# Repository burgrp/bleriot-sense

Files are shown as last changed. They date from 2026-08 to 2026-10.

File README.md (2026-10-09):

# BleRiot Sense

BleRiot Sense is a compact single-sensor BleRiot node built around a
`PY32F003L16S6TU` microcontroller and a PAN2110 long-range 2.4 GHz radio. Its
sensor input is configured at assembly time for one of four uses:

- A 10 kΩ B3950 NTC thermistor.
- A pulse-output flow sensor such as the YF-B10.
- A pressure sensor with a driven 0.5-5 V analog output.
- An externally powered DS18B20 digital thermometer.

The assembly population and the firmware mode must agree. The hardware does not
switch sensor modes electronically at runtime.

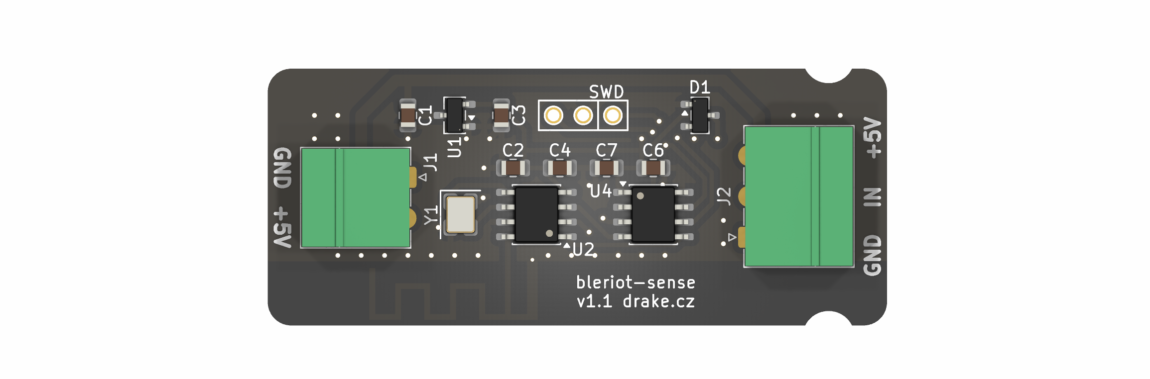
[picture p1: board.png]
BleRiot Sense board front render

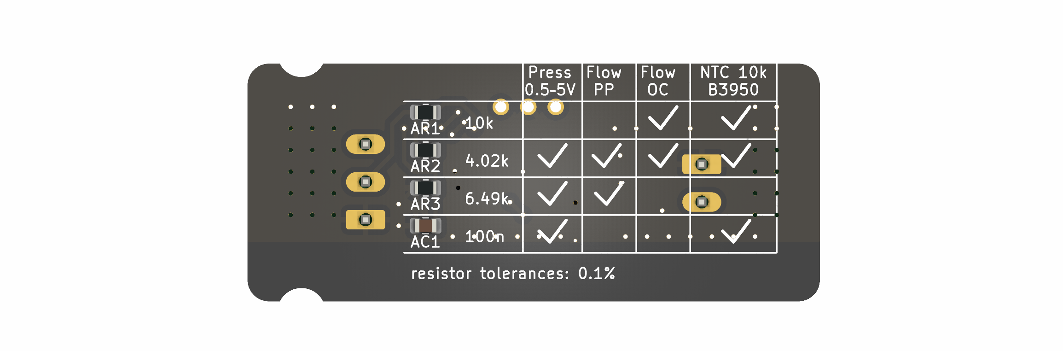
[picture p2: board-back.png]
BleRiot Sense board back with sensor-mode assembly table


## Repository layout

| Path | Description |
|---|---|
| [`board/bleriot-sense.kicad_pro`](board/bleriot-sense.kicad_pro) | `PY32F003L16S6TU` hardware |
| [`fw/`](fw/README.md) | Importable Sense firmware and board-owned build profile |
| [`fw/cmd/dev/`](fw/cmd/dev/) | Local inventory and BleRiot CLI |
| [`ANALOG-INPUT.md`](ANALOG-INPUT.md) | Configurable input circuit, populations, calculations, protection, and layout |
| [`sub/hw-kicad/`](sub/hw-kicad) | Shared KiCad symbols and footprints, included as a Git submodule |

## Sensor modes

| Mode | Node measurement | Registry value |
|---|---|---|
| NTC | Averaged 12-bit ADC code | Temperature in °C |
| Flow | Rising-edge pulse count | Frequency in Hz and cumulative pulse count |
| Pressure | Averaged 12-bit ADC code | Reconstructed sensor-output voltage in V |
| DS18B20 | Up to 20 signed Q12.4 scratchpad values | Temperature registers in °C |

See [`ANALOG-INPUT.md`](ANALOG-INPUT.md) before assembling a board. It defines
the required values for `AR1`, `AR2`, `AR3`, and `AC1`, including the two
alternative flow-sensor output circuits.

The pressure transfer function and flow K-factor depend on the exact sensor.
The hub currently exposes pressure input voltage and flow frequency without
assuming undocumented sensor calibration constants.

## Firmware status

[`fw`](fw/README.md) targets the `PY32F003L16S6TU` and uses `PA0` for
the universal sensor input. The NTC path has been verified end to end on
hardware through the ADC, PAN2110 radio, MCP2210 hub dongle, BleRiot hub,
conversion layer, and Registry. The single-sensor DS18B20 path has also been
verified end to end through its 1-Wire bus and the same radio/Registry path;
multidrop behavior still requires hardware validation. Flow and pressure support build and have
host-side conversion coverage but still require mode-specific hardware tests.

DS18B20 firmware prints discovered ROM IDs over RTT at boot. A single sensor
needs no configured ID; multidrop inventories map each temperature register to
an explicit ID. See the firmware README for configuration and timing details.

The upstream TinyGo `py32f003x6` target provides the required 1 KiB system
stack. The firmware runs without a task scheduler. See the firmware README for
pin assignments, first-boot option-byte handling, configuration, and memory
constraints.

## Getting started

Initialize the shared KiCad library after cloning:

```sh
git submodule update --init --recursive
```

Open the hardware project in KiCad:

```sh
kicad board/bleriot-sense.kicad_pro
```

Configure `sensorMode` in
[`fw/cmd/dev/main.go`](fw/cmd/dev/main.go), then test and build the firmware:

```sh
go -C fw test ./...
go -C fw run ./cmd/dev node build --name sense
```

Flash with a supported SWD probe:

```sh
go -C fw run ./cmd/dev node build --name sense --flash --rtt
```

With a Registry server running, start the hub in a separate terminal:

```sh
go -C fw run ./cmd/dev hub --registry http://localhost:8080 --diagnostics rf
```

For an NTC-configured node, read live temperatures:

```bash
export REGISTRY=http://localhost:8080
reg get sense.temperature --stay
```

## Toolchain

- KiCad 10 for the hardware projects.
- Go 1.25.2 or newer for the firmware inventory, generator, tests, and hub.
- TinyGo with the Puya `py32f003x6` target.
- pyOCD with the Puya CMSIS pack and a supported SWD probe.
- An MCP2210/PAN2110 BleRiot hub dongle for RF operation.
- The [`reg`](https://github.com/burgrp/reg) Registry service and CLI.

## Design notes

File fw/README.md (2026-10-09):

# BleRiot Sense firmware

This module is the importable BleRiot Sense firmware and local inventory for the
`PY32F003L16S6TU` hardware in `board`.

External hubs import the versioned device specification as:

```go
import sense "github.com/burgrp/bleriot-sense/fw/v2/spec"
```

- MCU: `PY32F003L16S6TU` (32 KiB flash, 4 KiB RAM).
- TinyGo and pyOCD target: `py32f003x6`.
- Sensor input: `PA0`.
- PAN2110 SCK: `PA1`.
- PAN2110 DATA: `PA2`.
- PAN2110 CSN: `PB0`.

## Sensor mode

Set `senseConfig` in `cmd/dev/main.go` to match the assembled input network.
Build the device type from the same value so its register table matches the
baked firmware configuration:

```go
var senseConfig = spec.Config{
	Mode:                       spec.ModeNTC,
	SampleIntervalMilliseconds: 1000,
	ADCSamples:                 16,
}

Type:   spec.TypeForConfig(senseConfig, spec.Calibration{}),
Config: senseConfig,
```

Supported values are:

| Mode | Assembly population | Registry values |
|---|---|---|
| `spec.ModeNTC` | AR1 10 kΩ, AR2 4.02 kΩ, AR3 DNP, AC1 100 nF | `temperature` in °C |
| `spec.ModeFlow` | Driven: AR1 DNP, AR2 4.02 kΩ, AR3 6.49 kΩ, AC1 DNP; open collector: AR1 10 kΩ, AR2 4.02 kΩ, AR3/AC1 DNP | `frequency` in Hz and cumulative `pulses` |
| `spec.ModePressure` | AR1 DNP, AR2 4.02 kΩ, AR3 6.49 kΩ, AC1 100 nF | Sensor-output `voltage` in V |
| `spec.ModeDS18B20` | AR1 4.7 kΩ, AR2 100 Ω, AR3/AC1 DNP | `temperature` in °C |

The mode is inventory-as-code and is baked into the image by `node build`. It
does not electronically change the assembly population at runtime. Rebuild and
flash the node after changing it.

NTC and pressure calculations run in the hub; the node transmits averaged raw
12-bit ADC codes. Flow frequency is transmitted in millihertz and converted to
hertz by the hub. A sensor-specific pressure transfer function or flow K-factor
can be added to the host conversion once the exact sensor calibration is known.

DS18B20 mode supports up to 20 externally powered devices. Connect all sensors
in parallel: J2 pin 1 to GND, pin 2 to DQ, and pin 3 to VDD. DQ is pulled up to
3.3 V; do not connect a 5 V DQ pull-up. Parasite power is not supported.

At every boot, firmware enumerates the bus and prints copy-pasteable IDs over
RTT before starting the radio:

```text
DS18B20 ID: [8]byte{40, 255, 100, 30, 147, 22, 4, 128}
```

One temperature register needs no configured ID. It binds automatically only
when exactly one DS18B20 is discovered. For multiple registers, configure every
ID in register order:

```go
var senseConfig = spec.Config{
	Mode:                       spec.ModeDS18B20,
	SampleIntervalMilliseconds: 1000,
	DS18B20Sensors: []spec.DS18B20Sensor{
		{ID: [8]byte{40, 255, 100, 30, 147, 22, 4, 128}},
		{ID: [8]byte{40, 2, 2, 3, 4, 5, 6, 199}},
	},
}
```

Optional per-register calibration is supplied only when constructing the host
device type. It is not part of `spec.Config`, is not baked into firmware, and
does not alter the signed Q12.4 value returned by the node:

```go
var senseCalibration = spec.Calibration{
	DS18B20: map[int]float64{
		3: 1,
	},
}

Type:   spec.TypeForConfig(senseConfig, senseCalibration),
Config: senseConfig,
```

The hub publishes $raw/16 + OffsetCelsius$. Supply either no calibration entries
or sparse offsets keyed by one-based DS18B20 sensor index, matching register names
such as `temperature.3`. Indexes must identify configured registers, offsets must
be finite, and nonzero offsets are included in Registry metadata as
`offsetCelsius`.

DS18B20 registers use the dedicated contiguous tag range 256–275. A one-register
inventory uses `temperature`; a multidrop inventory uses `temperature.1` through
`temperature.20`. Generic sample tag 1 and flow pulse-count tag 2 remain separate.
Per-instance `RegistryNames` may assign meaningful deployment names without
changing these wire identities.

The node validates ROM and scratchpad CRCs and transmits signed Q12.4 values.
It broadcasts one conversion, waits 800 ms while polling the radio, then reads
one addressed sensor per main-loop pass. One 12-bit addressed read takes about
11.7 ms; `bleNode.Poll()` runs between reads, so 20 sensors do not create one
continuous roughly 234 ms radio blackout. With all 20 sensors, the 800 ms
conversion plus addressed reads stretches a nominal 1 s cycle to about 1.04 s.
A failed sensor becomes null without invalidating successful readings from the
other sensors.

The protocol implementation comes from `github.com/burgrp/tinygo-drivers/onewire`.
This board supplies only the PA0 open-drain, TIM3 1 MHz counter, and interrupt
adapter in `onewire_py32.go`.

The node retains the latest full-resolution sample for scheduled GET responses.
In flow mode, the pulse interrupt only increments an in-memory counter; each
sample interval updates both the frequency and cumulative `pulses` register.

NTC and pressure modes reply with protocol NULL for averaged ADC codes at or
below 64 or at or above 4031. An open NTC is pulled high; an open pressure input
is pulled low. The pressure sensor's documented 0.5–5.25 V range remains inside
these thresholds. Hub-side NTC checks remain as a defensive fallback.

DS18B20 scratchpad/address failures null only the affected register. No-presence,
stuck-low, parasite-power, or broadcast-conversion failures null the whole bus.
Flow is the hardware exception: no pulses is electrically identical to an
unplugged sensor, so firmware preserves a valid `0 Hz` reading. True flow-sensor
presence detection requires an additional hardware signal or heartbeat.

## Build and run

From this directory:

```sh
go test ./...
go run ./cmd/dev node gen --name sense
go run ./cmd/dev node build --name sense --disassembly
go run ./cmd/dev node build --name sense --flash --rtt
```

Run the hub against a Registry server with:

```sh
go run ./cmd/dev hub --registry http://localhost:8080 --diagnostics rf
```

The build command creates a private module under `.bleriot/firmware/sense`,
generates the node entry point, and calls `sense.Run` with the RF identity and
baked `spec.Config`.

The upstream TinyGo `py32f003x6` target reserves a 1 KiB system stack. Firmware
uses `--scheduler none`; sensor acquisition shares the nonblocking node loop so
no heap-backed goroutine stacks are required.

## First boot

On the eight-pin package, the PAN2110 CSN pad is shared with `PF2-NRST`. On first
boot the firmware preserves all option bytes except `NRST_MODE`, changes that
one option to GPIO, and requests one option-byte reload reset. Later boots do
not write the option bytes. SWD remains available on the separate SWDIO and
SWCLK pads.

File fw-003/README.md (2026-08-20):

# BleRiot Sense firmware

This module is the BleRiot node and hub inventory for the `board-003` hardware
variant. The sibling `board-030` project uses a PY32F030 and requires separate
firmware.

External hubs import the versioned device specification as:

```go
import sense "github.com/burgrp/bleriot-sense/fw-003/spec"
```

- MCU: `PY32F003L16S6TU` (32 KiB flash, 4 KiB RAM).
- TinyGo and pyOCD target: `py32f003x6`.
- Sensor input: `PA0`.
- PAN2110 SCK: `PA1`.
- PAN2110 DATA: `PA2`.
- PAN2110 CSN: `PB0`.

## Sensor mode

Set `sensorMode` in `test-hub.go` to match the assembled input network. The
device type needs only that mode; timing and averaging remain inline in the
firmware configuration:

```go
const sensorMode = spec.ModeNTC

Type: spec.Type(sensorMode),
Config: spec.Config{
	Mode:                       sensorMode,
	SampleIntervalMilliseconds: 1000,
	ADCSamples:                 16,
	SampleHysteresis:           4,
},
```

Supported values are:

| Mode | Assembly population | Registry values |
|---|---|---|
| `spec.ModeNTC` | AR1 10 kΩ, AR2 4.02 kΩ, AR3 DNP, AC1 100 nF | `temperature` in °C |
| `spec.ModeFlow` | Driven: AR1 DNP, AR2 4.02 kΩ, AR3 6.49 kΩ, AC1 DNP; open collector: AR1 10 kΩ, AR2 4.02 kΩ, AR3/AC1 DNP | `frequency` in Hz and cumulative `pulses` |
| `spec.ModePressure` | AR1 DNP, AR2 4.02 kΩ, AR3 6.49 kΩ, AC1 100 nF | Sensor-output `voltage` in V |

The mode is inventory-as-code and is baked into the image by `bleriot make`. It
does not electronically change the assembly population at runtime. Rebuild and
flash the node after changing it.

NTC and pressure calculations run in the hub; the node transmits averaged raw
12-bit ADC codes. Flow frequency is transmitted in millihertz and converted to
hertz by the hub. A sensor-specific pressure transfer function or flow K-factor
can be added to the host conversion once the exact sensor calibration is known.

`SampleHysteresis` reduces RF traffic by comparing each sample with the last
notified sample. A notification is sent only when the absolute difference is at
least the configured threshold. `0` and `1` preserve notification on every raw
change. The threshold uses node wire units: ADC counts in NTC and pressure
modes, and millihertz in flow mode. The example value of four ADC counts is
approximately 0.09 °C near 25 °C for the specified thermistor. GET responses
retain the latest full-resolution sample.

In flow mode, the pulse interrupt only increments an in-memory counter. The
cumulative `pulses` register is sampled and can notify at most once per sample
interval while pulses are arriving; it does not send one notification per
physical pulse. `SampleHysteresis` applies to `frequency`, not to `pulses`.

## Build and run

From this directory:

```sh
go test ./...
go run . make sense build
go run . make sense flash
```

Run the hub against a Registry server with:

```sh
go run . hub --registry http://localhost:8080 --diagnostics rf
```

The build command generates the ignored `main_gen.go` containing the node's RF
identity and baked `spec.Config`.

The upstream TinyGo `py32f003x6` target reserves a 1 KiB system stack. Firmware
uses `--scheduler none`; sensor acquisition shares the nonblocking node loop so
no heap-backed goroutine stacks are required.

## First boot

On the eight-pin package, the PAN2110 CSN pad is shared with `PF2-NRST`. On first
boot the firmware preserves all option bytes except `NRST_MODE`, changes that
one option to GPIO, and requests one option-byte reload reset. Later boots do
not write the option bytes. SWD remains available on the separate SWDIO and
SWCLK pads.

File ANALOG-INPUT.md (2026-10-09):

# Universal sensor input

## Purpose

The board uses one configurable input circuit for four mutually exclusive sensor modes:

1. A pressure sensor with a driven 0.5–5 V analog output.
2. A YF-B10 flow sensor with a pulse output.
3. An external 10 kΩ, B3950 NTC thermistor.
4. An externally powered DS18B20 digital thermometer.

The operating mode is selected by component population when the board is assembled. It is not switched electronically at runtime.

## Common circuit

```text
                        AR1
                 +3V3 ─/\/\/─+
                              |
                              +──── INPUT ─── AR2 ───+──── SENSOR_OUT ─── MCU
                              |                     |
                       external sensor              +── AR3 ── GND
                              |                     |
                             GND                    +── AC1 ── GND
```

`AR3` and `AC1` are separate parallel branches from `SENSOR_OUT` to ground. They are not connected in series.

The sensor connector should provide:

| Pin | Signal | Description |
|---:|---|---|
| 1 | `GND` | Sensor ground |
| 2 | `INPUT` | Driven sensor output, flow pulse, NTC terminal, or DS18B20 DQ |
| 3 | `+5V_SENSOR` | Supply for a pressure, flow, or DS18B20 sensor |

In NTC mode, the thermistor connects between `INPUT` and ground. The `+5V_SENSOR` pin is unused. `AR1` connects to regulated `+3V3`, making the measurement ratiometric with the MCU ADC supply.

## Recommended component values

| Component | Nominal value | Function |
|---|---:|---|
| AR1 | 10.0 kΩ, 0.1% | NTC or open-collector flow pull-up |
| AR2 | 4.02 kΩ, 0.1% | Input scaling, isolation, and fault-current limiting |
| AR3 | 6.49 kΩ, 0.1% | Lower resistor of the 5 V input divider |
| AC1 | 100 nF | Analog low-pass filter |

Use low-temperature-coefficient resistors for pressure and temperature measurement. One-percent parts may be sufficient if the assembled board is calibrated.

## Population table

| Mode | AR1 | AR2 | AR3 | AC1 | MCU input mode |
|---|---:|---:|---:|---:|---|
| Pressure, 0.5–5 V | DNP | 4.02 kΩ | 6.49 kΩ | 100 nF | ADC |
| Flow, driven 5 V output | DNP | 4.02 kΩ | 6.49 kΩ | DNP | GPIO/timer |
| Flow, open collector | 10.0 kΩ | 4.02 kΩ | DNP | DNP | GPIO/timer |
| NTC 10k B3950 | 10.0 kΩ | 4.02 kΩ | DNP | 100 nF | ADC |
| DS18B20 | 4.7 kΩ | 100 Ω | DNP | DNP | Open-drain GPIO |

The two flow populations are alternatives. Select one only after confirming the electrical output of the exact YF-B10 variant.

The DS18B20 population uses different resistor values from every analog mode.
Do not fit the default 4.02 kΩ `AR2` or 100 nF `AC1` in this mode.
The v1.2 board's back-side assembly legend predates DS18B20 support; use this
table rather than the values printed beside the footprints for a DS18B20 build.

## Pressure mode

### Population and connection

- Do not populate `AR1`.
- Populate `AR2` with 4.02 kΩ.
- Populate `AR3` with 6.49 kΩ.
- Populate `AC1` with 100 nF.
- Configure the MCU pin as an ADC input.
- Power the pressure sensor from `+5V_SENSOR` and connect its driven output to `INPUT`.

### Voltage scaling

`AR2` and `AR3` form a divider:

$$
V_{\mathrm{OUT}}=V_{\mathrm{INPUT}}\frac{R_{\mathrm{AR3}}}{R_{\mathrm{AR2}}+R_{\mathrm{AR3}}}
$$

For the recommended values:

$$
\frac{R_{\mathrm{AR3}}}{R_{\mathrm{AR2}}+R_{\mathrm{AR3}}}=\frac{6.49}{4.02+6.49}\approx0.6175
$$

| Sensor voltage | MCU voltage | Approximate 12-bit ADC code at 3.3 V |
|---:|---:|---:|
| 0.5 V | 0.309 V | 383 |
| 2.5 V | 1.544 V | 1916 |
| 4.5 V | 2.779 V | 3448 |
| 5.0 V | 3.087 V | 3831 |
| 5.25 V | 3.242 V | 4023 |

The original sensor voltage is recovered with:

$$
V_{\mathrm{INPUT}}=V_{\mathrm{OUT}}\frac{R_{\mathrm{AR2}}+R_{\mathrm{AR3}}}{R_{\mathrm{AR3}}}\approx1.6194V_{\mathrm{OUT}}
$$

The divider provides headroom for a nominal 5 V signal but does not make arbitrary overvoltage safe.

### Fault detection

`AR3` pulls `SENSOR_OUT` near ground when the pressure sensor or cable is
disconnected. The node replies with null for averaged ADC codes at or below 64
or at or above 4031. These thresholds are outside the documented 0.5–5.25 V
input range: its approximate codes are 383–4023.

### Filtering

For a low-impedance sensor output, the resistance driving `AC1` is approximately:

$$
R_{\mathrm{TH}}=R_{\mathrm{AR2}}\parallel R_{\mathrm{AR3}}\approx2.48\ \mathrm{k\Omega}
$$

With 100 nF:

$$
f_c=\frac{1}{2\pi R_{\mathrm{TH}}C_{\mathrm{AC1}}}\approx642\ \mathrm{Hz}
$$

$$
	au=R_{\mathrm{TH}}C_{\mathrm{AC1}}\approx248\ \mathrm{\mu s}
$$

Pressure normally changes slowly, so firmware can additionally average several ADC samples.

## Flow mode

The YF-B10 produces pulses whose frequency represents flow. The MCU pin must be configured as a digital GPIO interrupt, timer capture, or timer counter input—not as an ADC input. `AC1 = 100 nF` is not populated because it would slow pulse edges and could distort the duty cycle.

### Driven or internally pulled-up output

Use this population only if the exact sensor produces a driven pulse reaching approximately 5 V:

- Do not populate `AR1`.
- Populate `AR2` with 4.02 kΩ.
- Populate `AR3` with 6.49 kΩ.
- Do not populate `AC1`.

The divider applies the same scale factor as pressure mode:

$$
V_{\mathrm{HIGH,OUT}}\approx0.6175V_{\mathrm{HIGH,INPUT}}
$$

A 5 V pulse becomes approximately 3.09 V; a 4.5 V pulse becomes approximately 2.78 V.

The sensor drives a total divider resistance of:

$$
R_{\mathrm{AR2}}+R_{\mathrm{AR3}}=10.51\ \mathrm{k\Omega}
$$

At 5 V, its high-state load current is approximately:

$$
I=\frac{5}{10.51\ \mathrm{k\Omega}}\approx0.476\ \mathrm{mA}
$$

Confirm that the sensor can source this current and that 2.78 V is safely above the MCU's guaranteed digital-high threshold under all operating conditions.

### Open-collector output

Some YF-B10 variants are described as NPN/open-collector outputs. Such an output needs a pull-up:

- Populate `AR1` with 10 kΩ to `+3V3`.
- Populate `AR2` with 4.02 kΩ.
- Do not populate `AR3`.
- Do not populate `AC1`.

`AR1` pulls `INPUT` to 3.3 V while the sensor transistor pulls it to ground. Since the MCU input draws negligible DC current, there is almost no DC drop across `AR2`, and the MCU receives a nominal 0–3.3 V pulse.

Before choosing the production population, verify the exact sensor's:

- Supply-voltage range.
- Push-pull/open-collector output type.
- Internal pull-up, if any.
- Output-high voltage and source current.
- Maximum pulse frequency.
- Required external pull-up resistance.

An optional 100 pF–1 nF capacitor footprint can be added for high-frequency EMI suppression. Its effect on pulse shape and maximum measurable frequency must be verified before population.

Firmware calculates flow by counting pulses in a fixed interval or measuring the time between edges. Use the calibration constant for the exact sensor, preferably verified by system calibration.

A disconnected flow sensor cannot be distinguished from a connected sensor at
zero flow using this single pulse wire: both produce no edges and the same idle
level for the selected population. Firmware therefore preserves `0 Hz` when no
pulses arrive. Reliable disconnect reporting requires a separate presence
signal, a sensor heartbeat, or supply-current sensing.

## NTC mode

### Population and connection

- Populate `AR1` with 10.0 kΩ, preferably 0.1% and low temperature coefficient.
- Populate `AR2` with 4.02 kΩ.
- Do not populate `AR3`.
- Populate `AC1` with 100 nF.
- Configure the MCU pin as an ADC input.
- Connect the external 10 kΩ B3950 NTC from `INPUT` to ground.

The temperature divider is:

```text
+3V3 ── AR1 10k ── INPUT ── external NTC 10k B3950 ── GND
```

`AR2` isolates the cable-side divider from the ADC and forms a low-pass filter with `AC1`. Since the ADC draws negligible DC current, `AR2` causes almost no steady-state voltage drop.

### Resistance calculation

The nominal ADC voltage is:

$$
V_{\mathrm{OUT}}\approx V_{\mathrm{CC}}\frac{R_{\mathrm{NTC}}}{R_{\mathrm{AR1}}+R_{\mathrm{NTC}}}
$$

At 25 °C, both `AR1` and the NTC are nominally 10 kΩ, so:

$$
V_{\mathrm{OUT}}=3.3\frac{10\ \mathrm{k\Omega}}{10\ \mathrm{k\Omega}+10\ \mathrm{k\Omega}}=1.65\ \mathrm{V}
$$

Thermistor resistance can be recovered from voltage:

$$
R_{\mathrm{NTC}}=R_{\mathrm{AR1}}\frac{V_{\mathrm{OUT}}}{V_{\mathrm{CC}}-V_{\mathrm{OUT}}}
$$

For a 12-bit ADC using the same supply as its reference, use the ratiometric form:

$$
R_{\mathrm{NTC}}=R_{\mathrm{AR1}}\frac{N_{\mathrm{ADC}}}{4095-N_{\mathrm{ADC}}}
$$

This result is largely independent of the exact 3.3 V supply voltage.

### Temperature calculation

For a nominal 10 kΩ B3950 thermistor:

$$
T_K=\left[\frac{1}{298.15}+\frac{1}{3950}\ln\left(\frac{R_{\mathrm{NTC}}}{10000}\right)\right]^{-1}
$$

Convert kelvin to degrees Celsius with:

$$
T_C=T_K-273.15
$$

Approximate nominal values are:

| Temperature | NTC resistance | ADC voltage at 3.3 V |
|---:|---:|---:|
| −20 °C | 105 kΩ | 3.01 V |
| 0 °C | 33.6 kΩ | 2.54 V |
| 25 °C | 10.0 kΩ | 1.65 V |
| 50 °C | 3.59 kΩ | 0.87 V |
| 80 °C | 1.27 kΩ | 0.37 V |
| 100 °C | 0.70 kΩ | 0.21 V |

Use the thermistor manufacturer's resistance table or Steinhart–Hart coefficients when better accuracy is required.

### Filtering

At 25 °C, the approximate resistance driving `AC1` is:

$$
R_{\mathrm{TH}}=R_{\mathrm{AR2}}+(R_{\mathrm{AR1}}\parallel R_{\mathrm{NTC}})=4.02\ \mathrm{k\Omega}+5.00\ \mathrm{k\Omega}=9.02\ \mathrm{k\Omega}
$$

With 100 nF:

$$
f_c\approx\frac{1}{2\pi(9.02\ \mathrm{k\Omega})(100\ \mathrm{nF})}\approx176\ \mathrm{Hz}
$$

This is much faster than the thermal response of a typical probe. Firmware averaging can provide additional noise rejection.

### Fault detection

Firmware should treat readings near either ADC rail as possible faults:

- Near 0 V: shorted thermistor/cable or temperature above the intended range.
- Near 3.3 V: open thermistor/cable or temperature below the intended range.

The node replies with null for averaged 12-bit ADC codes at or below 64 and at
or above 4031. These thresholds are well outside the nominal −20…100 °C range
while leaving margin for ADC and component tolerances. The hub conversion keeps
the same checks as a defensive fallback.

## DS18B20 mode

### Population and connection

- Populate `AR1` with 4.7 kΩ to `+3V3`.
- Populate `AR2` with 100 Ω.
- Do not populate `AR3` or `AC1`.
- Keep the MCU-side `D1` rail clamp populated.
- Connect DS18B20 GND to J2 pin 1, DQ to pin 2, and VDD to pin 3 (`+5V_SENSOR`).

The DQ pull-up is 3.3 V even though the sensor is powered from 5 V. Do not use a
probe or breakout that pulls DQ up to 5 V: `PA0` is not 5 V tolerant. The 100 Ω
series resistor provides edge damping and limits clamp current without preventing
the MCU from meeting the DS18B20 low-level requirement.

Firmware supports up to 20 externally powered DS18B20s connected in parallel.
Parasite-powered operation is not supported because the board has no switched
strong pull-up. Firmware checks the bus power mode and leaves temperature
registers null when a parasite-powered device is detected.

For a long or highly capacitive cable, 2.2–3.3 kΩ may be required for `AR1`.
Qualify the actual sensor count, cable topology, and any alternative pull-up with
an oscilloscope at the connector; DQ must rise in time for the firmware's 10 µs
read sample. Do not populate `AC1` as an EMI filter on the 1-Wire bus.

### Firmware behavior

At boot the node enumerates the 1-Wire bus and prints every DS18B20 ID over RTT.
It configures each selected sensor for 12-bit resolution without writing EEPROM,
broadcasts one conversion, and polls the radio during the 800 ms conversion.
Addressed scratchpads are then read one per main-loop pass, with another radio
poll between sensors. It transports native signed Q12.4 words; the hub converts
them to degrees Celsius. A missing device, bad CRC, or out-of-range value nulls
only that sensor. A stuck-low bus or parasite-power fault nulls the whole bus
until a later cycle succeeds.

## Input protection

The common four-component network does not by itself provide complete protection. Recommended additions are:

```text
connector INPUT ── cable ESD device ── AR2 ── SENSOR_OUT ── MCU
                                               |
                                      low-leakage clamps
                                        to +3V3 and GND
```

- Put a cable-rated, low-capacitance ESD device next to the connector.
- Its working voltage must not load a valid 5–5.25 V signal at `INPUT`.
- Put low-leakage rail clamps close to `SENSOR_OUT` and the MCU.
- Orient the lower clamp from ground to `SENSOR_OUT` and the upper clamp from `SENSOR_OUT` to `+3V3`.
- Keep `AR2` before the MCU-side clamps so it limits fault current.
- Check the clamp leakage over temperature because it contributes analog measurement error.
- Check unpowered behavior: an energized sensor must not back-power the 3.3 V rail through the upper clamp.

The circuit is intended for normal 0–5 V signals and transient protection. It is not automatically safe against a sustained 12 V or 24 V wiring error.

## PCB layout

- Place the cable ESD device immediately behind the sensor connector.
- Give the ESD device a short, direct connection to the ground plane.
- Place `AC1`, `AR3`, and MCU-side clamps close to the MCU input.
- Keep `SENSOR_OUT` away from the RF antenna, crystal, clocks, LED data, and noisy supply-current paths.
- Avoid sharing the sensor ground-return path with high-current LED, radio, or regulator currents.
- Provide test points for `INPUT` and `SENSOR_OUT`.
- Clearly document the pressure, flow, NTC, and DS18B20 assembly populations on the schematic and BOM.

## Firmware summary

| Mode | MCU peripheral | Processing |
|---|---|---|
| Pressure | ADC | Average samples and reverse the divider ratio |
| Flow | GPIO/timer | Count edges or measure pulse period |
| NTC | ADC | Convert ADC ratio to resistance and then temperature |
| DS18B20 | Open-drain GPIO | 1-Wire conversion and CRC-checked scratchpad read |

The selected MCU pin must support ADC, interrupt input, and open-drain GPIO operation if all four populations are to use exactly the same physical input.

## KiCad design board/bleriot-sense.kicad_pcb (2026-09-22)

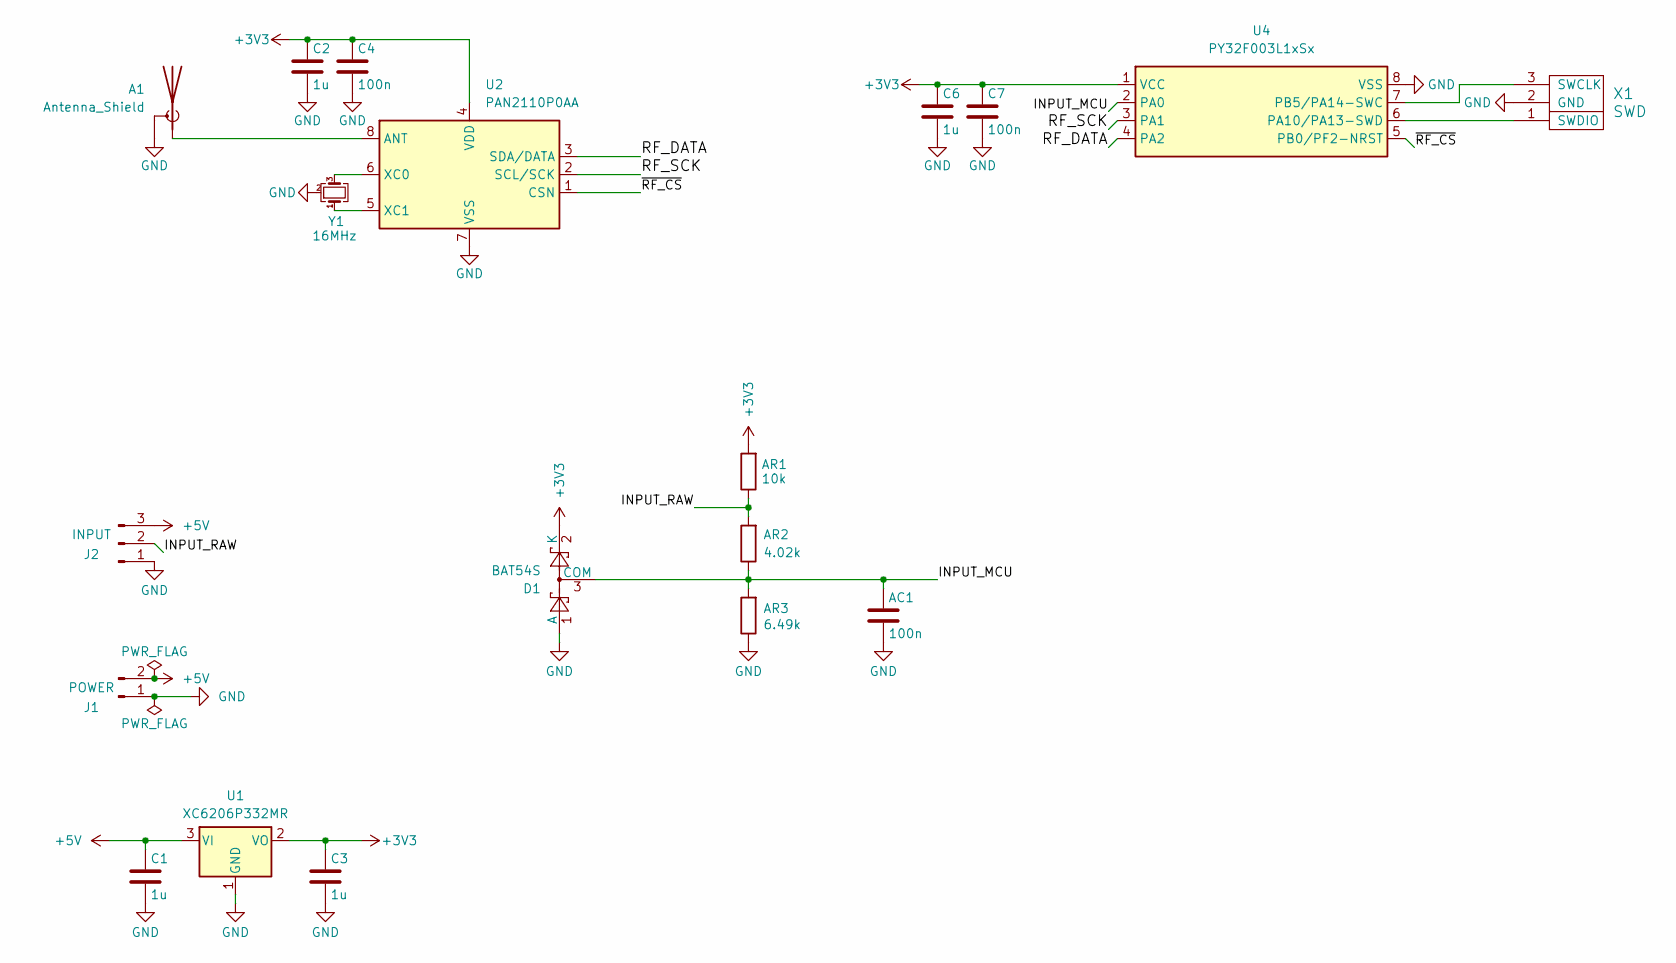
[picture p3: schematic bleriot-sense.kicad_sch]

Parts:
A1: Antenna_Shield; Texas_SWRA117D_2.4GHz_Left
AC1: 100n; C_0805_2012Metric
AR1: 10k; R_0805_2012Metric
AR2: 4.02k; R_0805_2012Metric
AR3: 6.49k; R_0805_2012Metric
C1, C2, C3, C6: 1u; C_0805_2012Metric
C4, C7: 100n; C_0805_2012Metric
D1: BAT54S; SOT-23
J1: POWER; PhoenixContact_MSTBA_2,5_2-G_1x02_P5.00mm_Horizontal
J2: INPUT; PhoenixContact_MSTBA_2,5_3-G_1x03_P5.00mm_Horizontal
U1: XC6206P332MR; SOT-23-3
U2: PAN2110P0AA; SOIC-8_3.9x4.9mm_P1.27mm
U4: PY32F003L1xSx; SOIC-8_3.9x4.9mm_P1.27mm
X1: SWD
Y1: 16MHz; Crystal_SMD_3225-4Pin_3.2x2.5mm

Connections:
+3V3: AR1.2, C2.1, C3.1, C4.1, C6.1, C7.1, D1.2 (K), U1.2 (VO), U2.4 (VDD), U4.1 (VCC)
+5V: C1.1, J1.2, J2.3, U1.3 (VI)
/INPUT_MCU: AC1.1, AR2.1, AR3.2, D1.3 (COM), U4.2 (PA0)
/INPUT_RAW: AR1.1, AR2.2, J2.2
/RF_DATA: U2.3 (SDA/DATA), U4.4 (PA2)
/RF_SCK: U2.2 (SCL/SCK), U4.3 (PA1)
/~RF_CS: U2.1 (CSN), U4.5 (PB0/PF2-NRST)
GND: A1.2 (Shield), AC1.2, AR3.1, C1.2, C2.2, C3.2, C4.2, C6.2, C7.2, D1.1 (A), J1.1, J2.1, U1.1 (GND), U2.7 (VSS), U4.8 (VSS), X1.2 (GND), Y1.2 (G), Y1.4 (G)
unnamed: A1.1 (A), U2.8 (ANT)
unnamed: U2.6 (XC0), Y1.3
unnamed: U2.5 (XC1), Y1.1
unnamed: U4.6 (PA10/PA13-SWD), X1.1 (SWDIO)
unnamed: U4.7 (PB5/PA14-SWC), X1.3 (SWCLK)

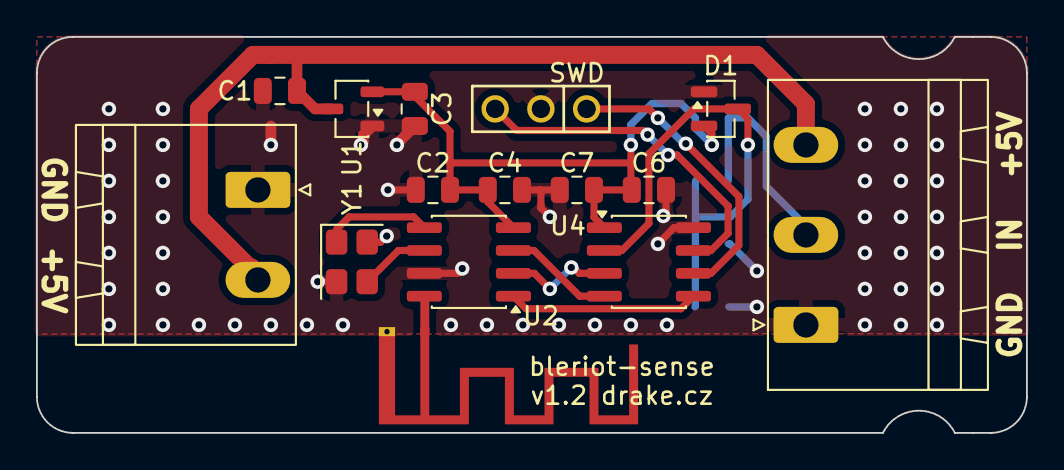
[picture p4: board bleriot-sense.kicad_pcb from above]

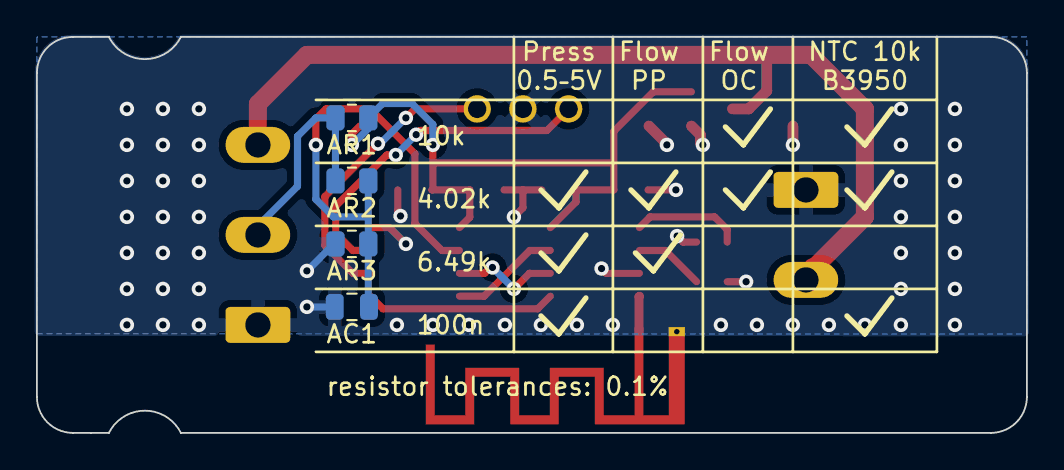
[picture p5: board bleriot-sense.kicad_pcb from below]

Board: 2 copper layers, 55.0 x 22.0 mm, 19 parts (4 on the bottom side), 13 nets.

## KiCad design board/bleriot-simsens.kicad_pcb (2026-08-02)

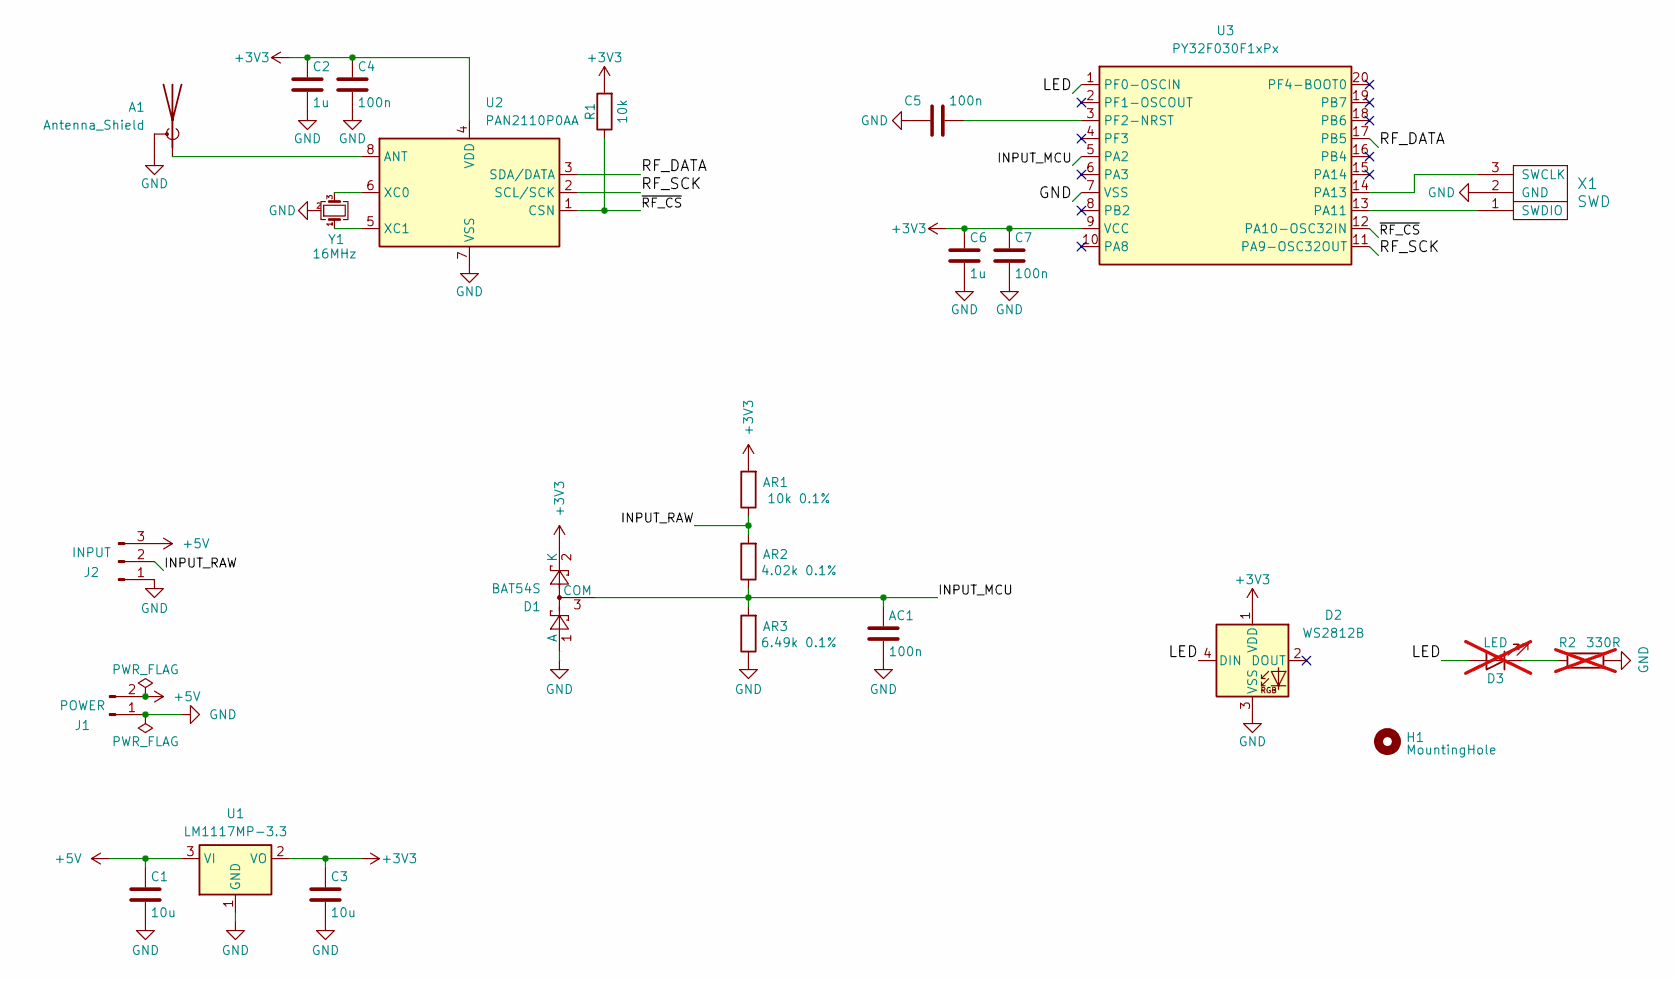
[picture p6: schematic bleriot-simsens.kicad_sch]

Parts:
A1: Antenna_Shield; Texas_SWRA117D_2.4GHz_Right
AC1: 100n; C_0805_2012Metric
AR1: 10k 0.1%; R_0805_2012Metric
AR2: 4.02k 0.1%; R_0805_2012Metric
AR3: 6.49k 0.1%; R_0805_2012Metric
C1, C3: 10u; C_0805_2012Metric
C2, C6: 1u; C_0805_2012Metric
C4, C5, C7: 100n; C_0805_2012Metric
D1: BAT54S; SOT-23
D2: WS2812B; LED_WS2812B_PLCC4_5.0x5.0mm_P3.2mm
D3: LED; LED_0805_2012Metric_Pad1.15x1.40mm_HandSolder; not fitted
H1: MountingHole; MountingHole_3.7mm_Pad_Via
J1: POWER; PhoenixContact_MSTBA_2,5_2-G_1x02_P5.00mm_Horizontal
J2: INPUT; PhoenixContact_MSTBA_2,5_3-G_1x03_P5.00mm_Horizontal
R1: 10k; R_0805_2012Metric
R2: 330R; R_0805_2012Metric; not fitted
U1: LM1117MP-3.3; SOT-223-3_TabPin2
U2: PAN2110P0AA; SOIC-8_3.9x4.9mm_P1.27mm
U3: PY32F030F1xPx; TSSOP-20_4.4x6.5mm_P0.65mm
X1: SWD
Y1: 16MHz; Crystal_SMD_3225-4Pin_3.2x2.5mm

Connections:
+3V3: AR1.2, C2.1, C3.1, C4.1, C6.1, C7.1, D1.2 (K), D2.1 (VDD), R1.2, U1.2 (VO), U2.4 (VDD), U3.9 (VCC)
+5V: C1.1, J1.2, J2.3, U1.3 (VI)
/INPUT_MCU: AC1.1, AR2.1, AR3.2, D1.3 (COM), U3.5 (PA2)
/INPUT_RAW: AR1.1, AR2.2, J2.2
/LED: D2.4 (DIN), D3.2 (A), U3.1 (PF0-OSCIN)
/RF_DATA: U2.3 (SDA/DATA), U3.17 (PB5)
/RF_SCK: U2.2 (SCL/SCK), U3.11 (PA9-OSC32OUT)
/~RF_CS: R1.1, U2.1 (CSN), U3.12 (PA10-OSC32IN)
GND: A1.2 (Shield), AC1.2, AR3.1, C1.2, C2.2, C3.2, C4.2, C5.2, C6.2, C7.2, D1.1 (A), D2.3 (VSS), J1.1, J2.1, R2.1, U1.1 (GND), U2.7 (VSS), U3.7 (VSS), X1.2 (GND), Y1.2 (G), Y1.4 (G)
unnamed: A1.1 (A), U2.8 (ANT)
unnamed: D3.1 (K), R2.2
unnamed: U2.6 (XC0), Y1.3
unnamed: U2.5 (XC1), Y1.1
unnamed: U3.13 (PA11), X1.1 (SWDIO)
unnamed: U3.14 (PA13), X1.3 (SWCLK)
unnamed: C5.1, U3.3 (PF2-NRST)

Board: 2 copper layers, 25 parts (0 on the bottom side), 16 nets, no tracks yet.

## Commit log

2026-08-02 Add documentation for universal analog sensor input configuration and usage
2026-08-17 Add BleRiot sensor firmware
2026-08-17 Rename board variants and add project README
    [bleriot-sense.kicad_pcb, bleriot-sense.kicad_sch]
2026-08-17 Change sensor type API to use mode
2026-08-20 Add sample notification hysteresis
2026-08-22 Consolidate on PY32F003 board
    [bleriot-sense.kicad_pcb, bleriot-sense.kicad_sch]
2026-08-22 board fixes
    [bleriot-sense.kicad_pcb, bleriot-sense.kicad_sch]
2026-09-21 Handle NTC wiring faults in hub conversion
2026-09-21 Refine NTC temperature conversion logic and update test to check for exact value
2026-09-22 Update design rules and component footprints in Bleriot Sense board
    - Modified DRC exclusions for silk over copper layers to adjust coordinates.
    - Added a new DRC exclusion for starved thermal connections.
    - Changed the footprint of the RF antenna from right to left orientation.
    - Updated connector footprints for Phoenix connectors to reflect correct part numbers and dimensions.
    [bleriot-sense.kicad_pcb, bleriot-sense.kicad_sch]
2026-10-08 feat(fw): add DS18B20 sensor support
2026-10-09 feat(fw)!: add multidrop sensor support
2026-10-09 feat(fw): add host-side sensor calibration
2026-10-09 feat(docs): add DS18B20 sensor documentation
